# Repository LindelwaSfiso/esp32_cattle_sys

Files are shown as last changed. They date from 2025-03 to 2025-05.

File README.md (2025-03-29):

# Project Documentation: ESP32 Cattle Weighting System

## Introduction
This document provides a comprehensive guide to the "ESP32 Cattle Weighting System" project. It details the project's setup, how Django operates within it, the role of APIs, and an explanation of the Django folder structure. This project is aimed at cattle farmers who what to keep track of the cattle weight using an innovative and digital solution.

---

## 2. Project Requirements
- **Python 3.12:** Programming language for the backend.
- **Django:** Web framework for the backend server.
- **DjangoRestFramework:** Framework for creating APIs.
- **Arduino/ESP32/C++:** Used for the micro-controller aspect of the project.

---

## 3. Installation and Setup

### Backend Setup:
1. Clone the repository:
    ```shell
    $ git clone https://github.com/LindelwaSfiso/esp32_cattle_sys.git
    ```

2. Navigate to the server directory:
    ```shell
    $ cd server
    ```

3. Create a virtual environment and activate it:
    ```shell
    $ python -3.12 -m venv venv
    $ venv\scripts\activate
    ```

4. Install the required packages:
    ```shell
    $ (venv) pip install -r requirements.txt
    ```

5. Apply database migrations:
    ```shell
    $ (venv) manage.py migrate
    ```

6. Run the server:
    ```shell
    $ (venv) manage.py runserver 0.0.0.0:8000
    ```

### Backend CSS Files Setup:
1. Navigate to the server directory:
    ```shell
    $ cd server
    ```

2. Build the CSS files:
    ```shell
    $ npm run build # generates build CSS for the website
    ```

### Creating Administration Account:
1. Navigate to the admin directory:
    ```shell
    $ cd server
    ```

2. Activate the virtual environment:
    ```shell
    $ venv\scripts\activate
    ```

3. Create a superuser account:
    ```shell
    $ (venv) manage.py createsuperuser
    ```

---

## 4. ESP32 Setup
Follow the [ESP32 devtools setup guide](https://docs.espressif.com/projects/arduino-esp32/en/latest/installing.html) for installing and configuring the ESP32 microcontroller.

---

# References

1. https://randomhnerdtutorials.com/esp32-load-cell-hx711/
2. https://www.electronicwings.com/esp32/rfid-rc522-interfacing-with-esp32
3. https://esp32io.com/tutorials/esp32-servo-motor
3. https://randomnerdtutorials.com/esp32-esp8266-i2c-lcd-arduino-ide/
4. https://github.com/marcoschwartz/LiquidCrystal_I2C/archive/master.zip

# Arduino IDE Libraries
1. https://github.com/OSSLibraries/Arduino_MFRC522v2 MFRC522v2
2. https://github.com/bogde/HX711
3. esp32 board version 3.0.7
4. https://github.com/madhephaestus/ESP32Servo

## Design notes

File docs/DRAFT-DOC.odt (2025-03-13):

AUTOMATED CATTLE WEIGHING SYSTEM

Objectives

1. Uniquely identify each cow, through cow tags

2. Automatically weigh the cow, and record the weight

3. Collect recorded weights and upload to an online server with a database. Each weight is tagged with the corresponding cow unique tag as well as the date that day.

4. Have a web application for the owner to browse uploaded data.

5. The web application should have export functionality, for the owner to export recorded data as an Excel/Spreadsheet or PDF.

6. (Optional) Web application should analyze and plot recorded data, for simpler data analyses, so that the owner can see area to improve.

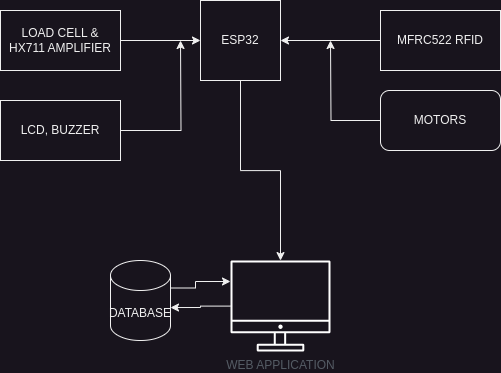
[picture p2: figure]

Suggested Components

1. ESP-32 Dev Board (should have WiFi capabilities)

2. MFRC522 RFID (for uniquely identifying each cow)

3. Load Cell and HX711 Amplifier (for weighing)

3.1 LCD for display, Buzzer for alert sounds

4. Motors to drive control gates when confining the cow for measurements

5. Remote Server with MySQL Database and Excel/PDF processing capabilities

6. Web Application UI to access, analyze, plot and browse the recorded data

Scenario

The farmer will register each cow RFID tag in the system remote database, unknown tags will be rejected. Each cow will have data like, sex, color, breed etc (having this data will be useful for analysis, etc. farmer can determine which breed is performing best...).

A cow enters the weighting system and is confined by two gates in-front and behind. Below is the load cell sensor. In-front of the cow, there is an RFID tag reader. The reader will detect the RFID tag of the cow from its ear, display the ID on an LCD, then verify if the cow is a valid tag and is available in the system. If the tag is valid and in the database, the weight is record and is sent to the remote server, the server saves the weight, date and RFID ID.

Once the server acknowledges that the data was saved successfully, the front motor opens, the cow gets out and the process repeats.

System Strict Limitation:

- no two cows can share the same RFID ID (should be unique)

- only weigh cows with valid tag, if the RFID is not in the system cow will not be weighed

- only one weight per day, if a multiple measurements are made, the system will overwrite the old data

- ADD MORE HERE

Pricing

- I’ll charge you 900 for esp32, connections, circuit and Arduino code

- The server and web application is way too much work, you could use ThinkSpeak (but I doubt you’ll get the excel processing and data validation). I can design a web application, database, excel integration and deploy to an online server, but it will be too much work, so I’ll charge 1200

- discount, final price you can pay is 1,400 and send a deposit as soon as you can

References

1. https://randomnerdtutorials.com/esp32-load-cell-hx711/

2. https://randomnerdtutorials.com/security-access-using-mfrc522-rfid-reader-with-arduino/

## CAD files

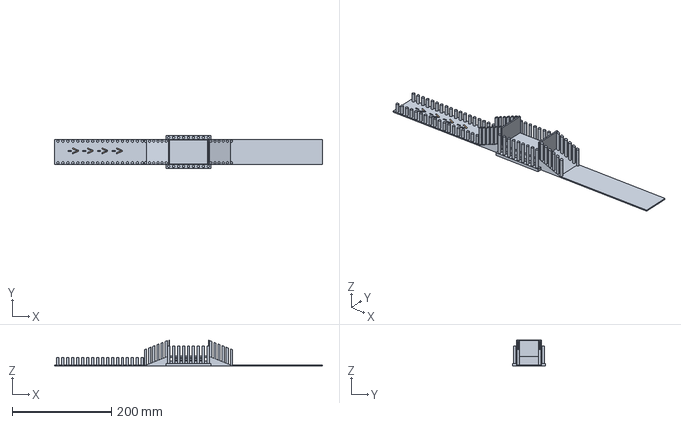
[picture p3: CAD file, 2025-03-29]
docs/PrototypeDesignNosmilo.FCStd
540.0 x 66.0 x 52.2 mm
ShapeString

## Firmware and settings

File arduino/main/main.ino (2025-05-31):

// Cattle Weighting System Arduino Code
// Date: 30 October 2023
// Electrical and Electronics

// Library imports
#include <WiFi.h>
#include <HTTPClient.h>

// mfrc522 rfid headers
#include <SPI.h>
#include <MFRC522.h>

// motors headers
#include <ESP32Servo.h>

// hx711 headers
#include "HX711.h"

// LCD
#include <LiquidCrystal_I2C.h>

// hx711 pin setup
#define LOADCELL_DOUT_PIN 16
#define LOADCELL_SCK_PIN 4

// mfrc522 rfid pin setup
#define SS_PIN 5
#define RST_PIN 3

// servo motors pins
#define OPEN_SERVO_PIN 25
#define CLOSE_SERVO_PIN 26


// push buttons pins
#define OPEN_BUTTON_PIN 17
#define CLOSE_BUTTON_PIN 27
#define PROCESS_BUTTON_PIN 13

// hx711 setup variables
#define SCALE_CALIBRATION_FACTOR 200.246674
#define SCALE_OFFSET_FACTOR 456154

const char* ssid = "Nosmilo";
const char* password = "76645417";


String serverName = "http://192.168.79.144:8000";        // Local HTTP Server
String uploadServerPath = serverName + "/api/upload/";  // HTTP endpoint for data upload


// Initialization
WiFiClient client;  // Local WiFi Client [HTTP]
HTTPClient http;

HX711 scale;
MFRC522 rfid(SS_PIN, RST_PIN);

MFRC522::MIFARE_Key key;

// setup LCD
LiquidCrystal_I2C lcd(0x27, 16, 2);

// motors setup
Servo openServo, closeServo;

// push button control state
unsigned long lastOpenDebounceTime = 0;
unsigned long lastCloseDebounceTime = 0;
unsigned long lastProcessDebounceTime = 0;
int lastOpenButtonState = HIGH;
int lastCloseButtonState = HIGH;
int lastProcessButtonState = HIGH;

// whether it is permited to open or close gates,
// this avoids opening a gate while we are weighing another cow
bool shouldOpenGates = true;

bool isOpenGateOpen = false;
bool isCloseGateOpen = false;
bool isCowPresentForProcessing = false;

void setup() {
  // put your setup code here, to run once:
  Serial.begin(115200);

  Serial.print("\nSetting up motors.......\n");
  // setup servo motors
  ESP32PWM::allocateTimer(0);
  ESP32PWM::allocateTimer(1);
  ESP32PWM::allocateTimer(2);
  ESP32PWM::allocateTimer(3);

  openServo.setPeriodHertz(50);   // standard 50 hz servo
  closeServo.setPeriodHertz(50);  // standard 50 hz servo

  openServo.attach(OPEN_SERVO_PIN, 900, 2100);
  closeServo.attach(CLOSE_SERVO_PIN, 900, 2100);

  openServo.write(0);
  closeServo.write(0);
  delay(1000);

  Serial.print("\nSetting up LCD.......\n");
  lcd.begin();
  lcd.backlight();

  lcd.clear();
  lcd.setCursor(0, 0);
  lcd.print("Connecting......");
  lcd.setCursor(0, 1);
  lcd.print(String(ssid));

  Serial.print("\nSetting up push buttons.......\n");
  pinMode(OPEN_BUTTON_PIN, INPUT_PULLUP);
  pinMode(CLOSE_BUTTON_PIN, INPUT_PULLUP);
  pinMode(PROCESS_BUTTON_PIN, INPUT_PULLUP);

  // initialize WiFi, and connect, later disable this to work with ADC pins
  WiFi.begin(ssid, password);
  Serial.print("Connecting..");
  while (WiFi.status() != WL_CONNECTED) {
    delay(500);
    Serial.print(".");
  }

  Serial.println("");
  Serial.print("Connected to WiFi network with IP Address: ");
  Serial.println(WiFi.localIP());
  Serial.println("\n");

  lcd.clear();
  lcd.setCursor(0, 0);
  lcd.print("Connected - WiFi");
  lcd.setCursor(0, 1);
  lcd.print(String(ssid));
  delay(1000);

  Serial.print("\nInitializing HX711 scale.......\n");
  scale.begin(LOADCELL_DOUT_PIN, LOADCELL_SCK_PIN);

  scale.set_offset(SCALE_OFFSET_FACTOR);
  scale.set_scale(SCALE_CALIBRATION_FACTOR);
  scale.tare();


  Serial.print("\nInitializing mrf522 rfid reader......\n");
  SPI.begin();      // Init SPI bus
  rfid.PCD_Init();  // Init MFRC522

  for (byte i = 0; i < 6; i++) {
    key.keyByte[i] = 0xFF;
  }

  Serial.println(F("This code scan the MIFARE Classsic NUID."));
  Serial.print(F("Using the following key:"));
  printHex(key.keyByte, MFRC522::MF_KEY_SIZE);
  Serial.println("\n");

  Serial.print("\nDONE SETUP, ENTERING LOOP PROCESS......\n");

  printGateStatus();
}

void loop() {
  // put your main code here, to run repeatedly:

  // check if the open button is pressed
  if (buttonPressed(OPEN_BUTTON_PIN, lastOpenButtonState, lastOpenDebounceTime) && shouldOpenGates) {
    // toogle the state of the OPENING gate
    // if it was previously open, close it, visa versa
    operateOpeningMotor(!isOpenGateOpen);

    // if we just closed the opening gate
    // we assume there is a cow in the scale therefore change the flag isCowPresentForProcessing to true
    float weight = getScaleReading();
    isCowPresentForProcessing = !isOpenGateOpen && !isCloseGateOpen && weight > 20;

    printGateStatus();
  }


  // check if the close button is pressed
  if (buttonPressed(CLOSE_BUTTON_PIN, lastCloseButtonState, lastCloseDebounceTime) && shouldOpenGates) {
    // toogle the state of the closing gate
    // if it was previously open, close it, visa versa
    operateClosingMotor(!isCloseGateOpen);

    // if the gate is open, we assume there is no cow for processing, visa versa
    float weight = getScaleReading();
    isCowPresentForProcessing = !isOpenGateOpen && !isCloseGateOpen && weight > 20;

    printGateStatus();
  }


  // we then check if the processing button is pressed
  // we also check if the isCowPresentForProcessing is true before processing the cow
  bool processButtonPressed = buttonPressed(PROCESS_BUTTON_PIN, lastProcessButtonState, lastProcessDebounceTime);
  if (processButtonPressed && isCowPresentForProcessing) {
    // process the cow
    readValuesAndUpload();
  }
}


void printGateStatus() {
  if (isCowPresentForProcessing) {
    lcd.clear();
    lcd.setCursor(0, 0);
    lcd.print("Cow Ready. Gates");
    lcd.setCursor(0, 1);
    lcd.print("Closed *press 3*");
  } else {
    lcd.clear();
    lcd.setCursor(0, 0);
    lcd.print("O. Gate:  ");
    lcd.print(isOpenGateOpen ? "OPEN" : "CLOSED");
    lcd.setCursor(0, 1);
    lcd.print("C. Gate:  ");
    lcd.print(isCloseGateOpen ? "OPEN" : "CLOSED");
  }
}


/** 
* Function to read rfid and weight readings and upload to the server
* attempt to wait 3 seconds for cow to get to position and align with the rfid
* and position itself on the scale then
* attempt to read the rfid, and the weight
*/
void readValuesAndUpload() {
  lcd.clear();
  lcd.setCursor(0, 0);
  lcd.print("Wait 2s for cow ");
  lcd.setCursor(0, 1);
  lcd.print("to settle proper");

  Serial.println("Delaying 2s for cow to settle down on the sacale and align with rfid correctly.......");
  delay(2000);

  // then read the rfid, and read the weight
  String readTag = readScannedCard();

  // if the tag is blank, we did not read anything, there is something wrong with the rfid
  // attempt to try notify farmer to position the cow correctly
  if (readTag.length() == 0) {
    Serial.println("Failed to read rfid, the cow is not positioned corrently, very far from the reader........");

    lcd.clear();
    lcd.setCursor(0, 0);
    lcd.print("Failed to get...");
    lcd.setCursor(0, 1);
    lcd.print("RFID Tag...Try a");
    
    return;  // fatal exit!
  }

  // get cow reading
  float weight = getScaleReading();

  if (weight < 0) {
    Serial.println("Failed to read weight, nothing on scale or scale is not working");

    lcd.clear();
    lcd.setCursor(0, 0);
    lcd.print("Failed to get...");
    lcd.setCursor(0, 1);
    lcd.print("WEIGHT...Try again");
    
    return;  // fatal exit!
  }

  // then upload
  bool isUploadSuccessful = remoteServerUploadData(weight, readTag);

  if (isUploadSuccessful) {
    // server upload was successful,
    Serial.println("Done Upload.... Open the closing gate.......");

    lcd.clear();
    lcd.setCursor(0, 0);
    lcd.print("Upload successful");
    lcd.setCursor(0, 1);
    lcd.print("opening C. Gate..");
    delay(2000);

    operateClosingMotor(!isCloseGateOpen);

    // update safety state
    isCowPresentForProcessing = !isOpenGateOpen && !isCloseGateOpen;

    printGateStatus();

  } else {
    // failed
    Serial.println("Failed to upload, try again.......");

    lcd.clear();
    lcd.setCursor(0, 0);
    lcd.print("Upload failed....");
    lcd.setCursor(0, 1);
    lcd.print("Try again........");
    delay(200);
  }
}

/***
Function to upload weight data to our remote server, 
returns true if the upload was successfull
*/
bool remoteServerUploadData(float weight, String rfid) {
  lcd.clear();
  lcd.setCursor(0, 0);
  lcd.print("Read data OKAY..");
  lcd.setCursor(0, 1);
  lcd.print("uploading.......");
  delay(200);

  bool isSuccessful = false;
  Serial.println("Uploading data to the server.....");

  // Confirm that ESP-32 is still connected to the WiFi
  if (WiFi.status() == WL_CONNECTED) {

    Serial.println("Connecting to server: " + serverName);
    http.begin(client, uploadServerPath.c_str());

    // for server authentication, if server APIs are protected
    // http.setAuthorization("SERVER_USERNAME", "SERVER_PASSWORD");

    // configure http, set content-type to JSON
    http.addHeader("Content-Type", "application/json");

    // Construct HTTP Request Payload with rfid and weight
    String requestData = "{\"rfid\": \"";
    requestData.concat(rfid);
    requestData.concat("\", ");
    requestData.concat("\"weight\": \"");
    requestData.concat(weight);
    requestData.concat("\"}");

    // Send HTTP POST Request, and Check response code
    int httpResponseCode = http.POST(requestData);

    // Check HTTP Response Code :: Success Status
    if (httpResponseCode == 200) {

      Serial.println("=> UPLOAD SUCCESSFUL");
      isSuccessful = true;

    } else {
      // Request was not successful, Print the reason why?
      Serial.println("FAILED TO UPLOAD: SERVER ERROR. AN ERROR OCCURRED: ");
      Serial.println(http.getString() + "\n");
    }


    // Free up Resources
    http.end();
  }

  else {
    Serial.println("FAILED TO UPLOAD: NOT CONNECTED TO ANY NETWORK!!!!");
  }

  return isSuccessful;
}


float getScaleReading() {
  Serial.print("Getting scale reading.....Weight: ");
  float weight = scale.get_units(10);
  
  Serial.print(weight);
  Serial.println(" g\n");

  return weight;
}


/**
* function to read a scanned rfid, return an empty string if there is no card or if we can't read the card
*/
String readScannedCard() {
  Serial.println("Getting scanned rfid card.....\n");

  // Reset the loop if no new card present on the sensor/reader. This saves the entire process when idle.
  if (!rfid.PICC_IsNewCardPresent())
    return "";

  // Verify if the NUID has been readed
  if (!rfid.PICC_ReadCardSerial())
    return "";

  Serial.print(F("PICC type: "));
  MFRC522::PICC_Type piccType = rfid.PICC_GetType(rfid.uid.sak);
  Serial.println(rfid.PICC_GetTypeName(piccType));

  // Check is the PICC of Classic MIFARE type
  if (piccType != MFRC522::PICC_TYPE_MIFARE_MINI && piccType != MFRC522::PICC_TYPE_MIFARE_1K && piccType != MFRC522::PICC_TYPE_MIFARE_4K) {
    Serial.println(F("Your tag is not of type MIFARE Classic."));
    return "";
  }

  Serial.println(F("A card has been detected."));
  String readNUID = getHexString(rfid.uid.uidByte, rfid.uid.size);
  Serial.println(F("The NUID tag is:"));
  Serial.print(F("In hex: "));
  Serial.println(readNUID);

  // Halt PICC
  rfid.PICC_HaltA();

  // Stop encryption on PCD
  rfid.PCD_StopCrypto1();

  // return the read nuid
  return readNUID;
}


/**
* Function to check if a button is pressed, note the button state is passed by reference 
*/
bool buttonPressed(int pin, int& lastButtonState, unsigned long& lastDebounceTime) {
  int buttonState = digitalRead(pin);
  if (buttonState != lastButtonState) {
    lastButtonState = buttonState;
    if (lastButtonState == LOW) {
      delay(500);
      return true;
    }
  }
  return false;
}


/**
 * Helper routine to dump a byte array as hex values to Serial. 
 */
void printHex(byte* buffer, byte bufferSize) {
  for (byte i = 0; i < bufferSize; i++) {
    Serial.print(buffer[i] < 0x10 ? " 0" : " ");
    Serial.print(buffer[i], HEX);
  }
}


/**
 * Helper routine to dump a byte array as dec values to Serial.
 */
void printDec(byte* buffer, byte bufferSize) {
  for (byte i = 0; i < bufferSize; i++) {
    Serial.print(' ');
    Serial.print(buffer[i], DEC);
  }
}


/**
* Helper function to convert the byte array to a hex value which is a string
*/
String getHexString(byte* buffer, byte bufferSize) {
  String hexString = "";
  for (byte i = 0; i < bufferSize; i++) {
    if (buffer[i] < 0x10) {
      hexString += "0";
    }
    char hexChar[3];                    // Buffer to store the hex representation
    sprintf(hexChar, "%X", buffer[i]);  // Convert byte to hex string
    hexString += hexChar;
  }
  return hexString;
}

void operateOpeningMotor(bool shouldOpen) {
  if (shouldOpen) {
    for (int pos = 0; pos <= 170; pos += 1) {  // goes from 0 degrees to 180 degrees
      openServo.write(pos);                    // tell servo to go to position in variable 'pos'
      delay(15);                               // waits 15ms for the servo to reach the position
    }
    Serial.println("Opening gate status: OPEN\n");
  } else {
    for (int pos = 170; pos >= 0; pos -= 1) {  // goes from 180 degrees to 0 degrees
      openServo.write(pos);                    // tell servo to go to position in variable 'pos'
      delay(15);                               // waits 15ms for the servo to reach the position
    }
    Serial.println("Opening gate status: CLOSED\n");
  }

  // update the state of the open servo motor
  isOpenGateOpen = shouldOpen;
}

void operateClosingMotor(bool shouldOpen) {
  if (shouldOpen) {
    for (int pos = 0; pos <= 170; pos += 1) {  // goes from 0 degrees to 180 degrees
      closeServo.write(pos);                   // tell servo to go to position in variable 'pos'
      delay(15);                               // waits 15ms for the servo to reach the position
    }
    Serial.println("Closing gate status: OPEN\n");

  } else {
    for (int pos = 170; pos >= 0; pos -= 1) {  // goes from 180 degrees to 0 degrees
      closeServo.write(pos);                   // tell servo to go to position in variable 'pos'
      delay(15);                               // waits 15ms for the servo to reach the position
    }
    Serial.println("Closing gate status: CLOSED\n");
  }

  // update the state of the close servo motor
  isCloseGateOpen = shouldOpen;
}

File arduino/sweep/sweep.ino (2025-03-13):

/* Sweep
 by BARRAGAN <http://barraganstudio.com>
 This example code is in the public domain.

 modified 8 Nov 2013
 by Scott Fitzgerald

 modified for the ESP32 on March 2017
 by John Bennett

 see http://www.arduino.cc/en/Tutorial/Sweep for a description of the original code

 * Different servos require different pulse widths to vary servo angle, but the range is 
 * an approximately 500-2500 microsecond pulse every 20ms (50Hz). In general, hobbyist servos
 * sweep 180 degrees, so the lowest number in the published range for a particular servo
 * represents an angle of 0 degrees, the middle of the range represents 90 degrees, and the top
 * of the range represents 180 degrees. So for example, if the range is 1000us to 2000us,
 * 1000us would equal an angle of 0, 1500us would equal 90 degrees, and 2000us would equal 1800
 * degrees.
 * 
 * Circuit: (using an ESP32 Thing from Sparkfun)
 * Servo motors have three wires: power, ground, and signal. The power wire is typically red,
 * the ground wire is typically black or brown, and the signal wire is typically yellow,
 * orange or white. Since the ESP32 can supply limited current at only 3.3V, and servos draw
 * considerable power, we will connect servo power to the VBat pin of the ESP32 (located
 * near the USB connector). THIS IS ONLY APPROPRIATE FOR SMALL SERVOS. 
 * 
 * We could also connect servo power to a separate external
 * power source (as long as we connect all of the grounds (ESP32, servo, and external power).
 * In this example, we just connect ESP32 ground to servo ground. The servo signal pins
 * connect to any available GPIO pins on the ESP32 (in this example, we use pin 18.
 * 
 * In this example, we assume a Tower Pro MG995 large servo connected to an external power source.
 * The published min and max for this servo is 1000 and 2000, respectively, so the defaults are fine.
 * These values actually drive the servos a little past 0 and 180, so
 * if you are particular, adjust the min and max values to match your needs.
 */

#include <ESP32Servo.h>

Servo myservo;  // create servo object to control a servo
// 16 servo objects can be created on the ESP32

int pos = 0;    // variable to store the servo position
// // Recommended PWM GPIO pins on the ESP32 include 2,4,12-19,21-23,25-27,32-33 
// // Possible PWM GPIO pins on the ESP32-S2: 0(used by on-board button),1-17,18(used by on-board LED),19-21,26,33-42
// // Possible PWM GPIO pins on the ESP32-S3: 0(used by on-board button),1-21,35-45,47,48(used by on-board LED)
// // Possible PWM GPIO pins on the ESP32-C3: 0(used by on-board button),1-7,8(used by on-board LED),9-10,18-21
// #if defined(CONFIG_IDF_TARGET_ESP32S2) || defined(CONFIG_IDF_TARGET_ESP32S3)
// int servoPin = 17;
// #elif defined(CONFIG_IDF_TARGET_ESP32C3)
// int servoPin = 7;
// #else
// int servoPin = 18;
// #endif


int servoPin = 25;

void setup() {
	// Allow allocation of all timers
	ESP32PWM::allocateTimer(0);
	ESP32PWM::allocateTimer(1);
	ESP32PWM::allocateTimer(2);
	ESP32PWM::allocateTimer(3);
	myservo.setPeriodHertz(50);    // standard 50 hz servo
	myservo.attach(servoPin, 500, 2500); // attaches the servo on pin 18 to the servo object
	// using default min/max of 1000us and 2000us
	// different servos may require different min/max settings
	// for an accurate 0 to 180 sweep
}

void loop() {

	for (pos = 0; pos <= 180; pos += 1) { // goes from 0 degrees to 180 degrees
		// in steps of 1 degree
		myservo.write(pos);    // tell servo to go to position in variable 'pos'
		delay(5);             // waits 15ms for the servo to reach the position
	}
	for (pos = 180; pos >= 0; pos -= 1) { // goes from 180 degrees to 0 degrees
		myservo.write(pos);    // tell servo to go to position in variable 'pos'
		delay(5);             // waits 15ms for the servo to reach the position
	}
}

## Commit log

2024-10-30 Added arduino code: incomplete and missing logic
    [main.ino, read_rfid_nuid.ino]
2025-03-29 add esp32 sample codes
2025-03-29 updated main code[incomplete]
    [PrototypeDesignNosmilo.FCStd]
2025-03-30 fixed arduino main code
    [main.ino]
2025-04-03 fixed arduino code
2025-05-31 fixed code and server and formula calculations
    [main.ino]
